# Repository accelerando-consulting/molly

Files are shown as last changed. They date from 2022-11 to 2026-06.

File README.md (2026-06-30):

# Molly - an i2c keypad module

This is intended either to fit your existing microcontroller or be added to an off the
shelf microcontroller board to make  a standalone keypad (eg the TTGO T7-S3 is a good choice of board).

Theres some simple python code in here, but
you should probably consider the [ZMK firmware](https://github.com/zmkfirmware/zmk) as the best starting point.

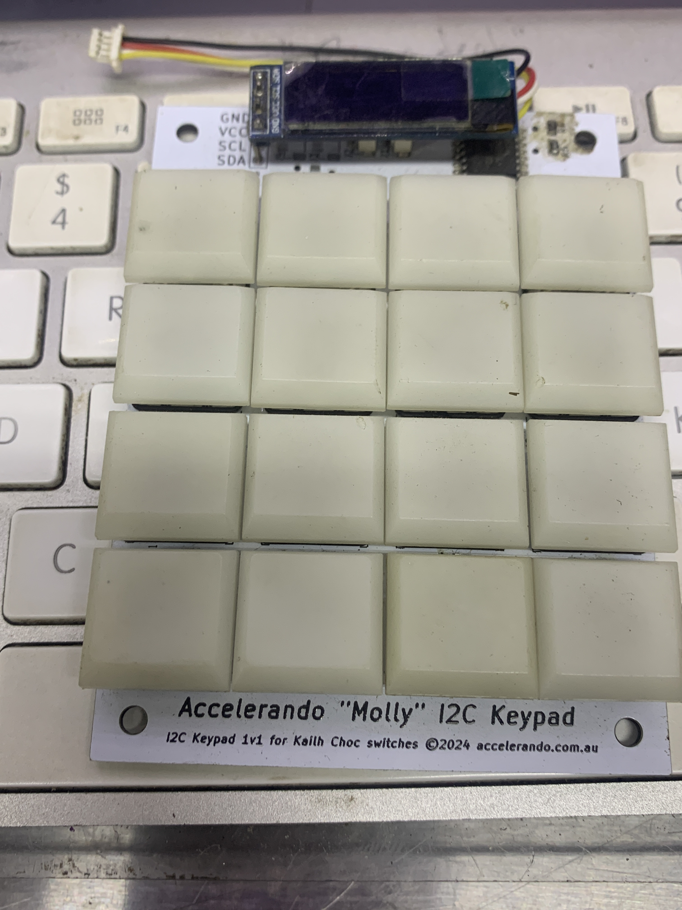
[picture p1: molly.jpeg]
Photograph of the assembled Molly PCB


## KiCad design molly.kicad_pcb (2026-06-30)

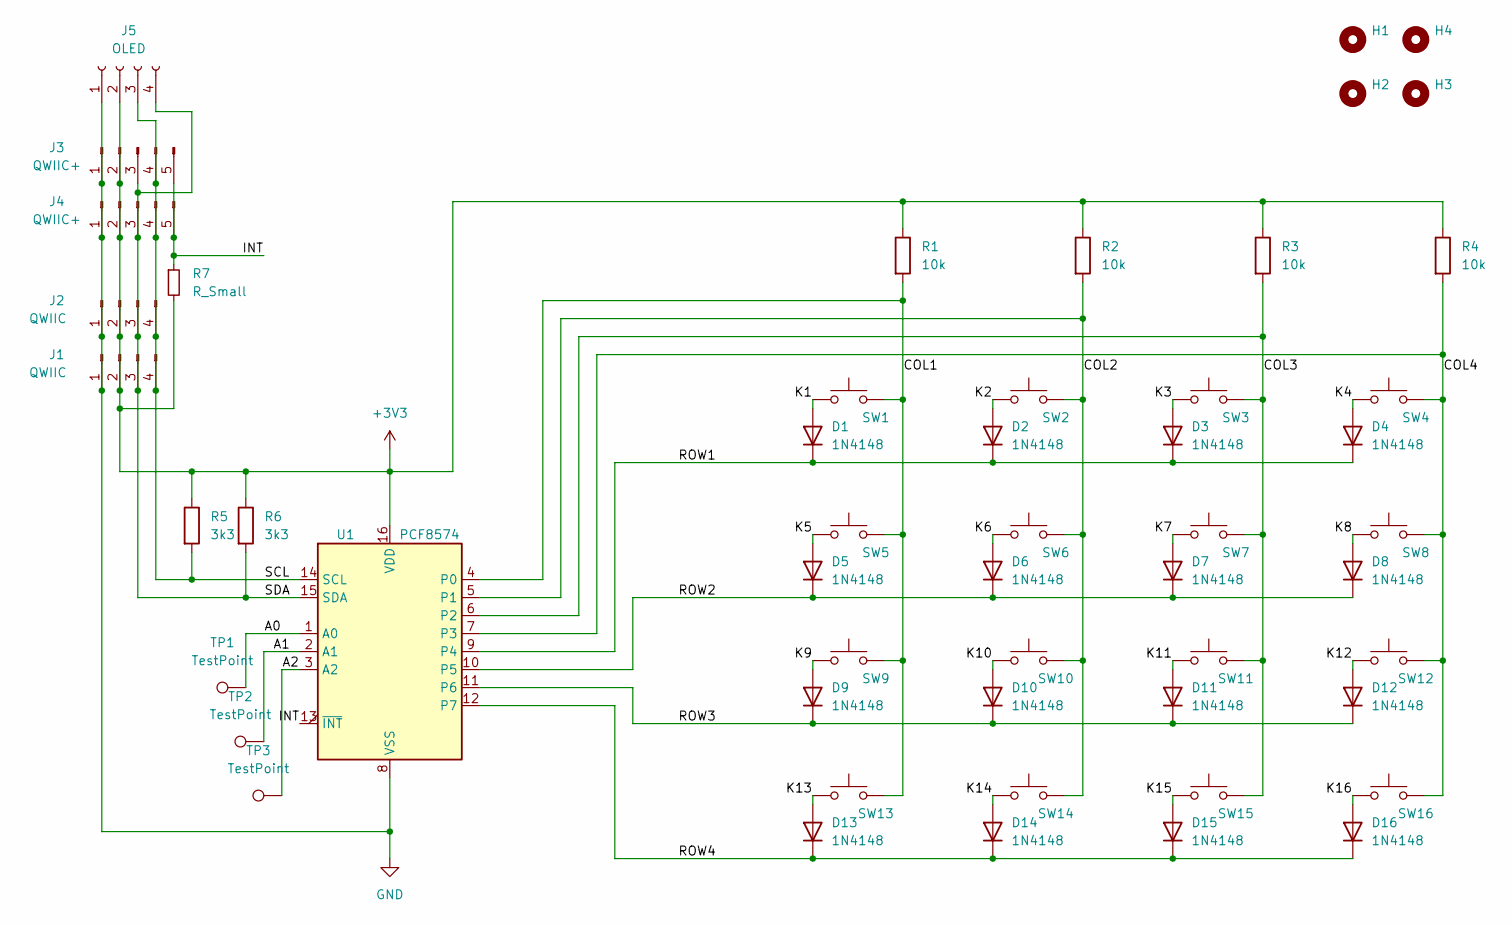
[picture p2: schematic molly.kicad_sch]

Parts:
D1, D2, D3, D4, D5, D6, D7, D8, D9, D10, D11, D12, D13, D14, D15, D16: 1N4148; D_0805_2012Metric
H1, H2, H3, H4: MountingHole; MountingHole_3.2mm_M3
J1, J2: QWIIC; JST_SH_BM04B-SRSS-TB_1x04-1MP_P1.00mm_Vertical
J3, J4: QWIIC+; JST_SH_BM05B-SRSS-TB_1x05-1MP_P1.00mm_Vertical
J5: OLED; PinSocket_1x04_P2.54mm_Vertical
R1, R2, R3, R4: 10k; R_0805_2012Metric
R5, R6: 3k3; R_0805_2012Metric
R7: R_Small; R_0805_2012Metric
SW1, SW2, SW3, SW4, SW5, SW6, SW7, SW8, SW9, SW10, SW11, SW12, SW13, SW14, SW15, SW16: Cherry MX; SW_PG1350
TP1, TP2, TP3: TestPoint; TestPoint_THTPad_2.0x2.0mm_Drill1.0mm
U1: PCF8574; SOIC-16W_7.5x10.3mm_P1.27mm

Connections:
+3V3: J1.2, J2.2, J3.2, J4.2, J5.2, R1.1, R2.1, R3.1, R4.1, R5.1, R6.1, R7.2, U1.16 (VDD)
/A0: TP1.1, U1.1 (A0)
/A1: TP2.1, U1.2 (A1)
/A2: TP3.1, U1.3 (A2)
/COL1: R1.2, SW1.2, SW5.2, SW9.2, SW13.2, U1.4 (P0)
/COL2: R2.2, SW2.2, SW6.2, SW10.2, SW14.2, U1.5 (P1)
/COL3: R3.2, SW3.2, SW7.2, SW11.2, SW15.2, U1.6 (P2)
/COL4: R4.2, SW4.2, SW8.2, SW12.2, SW16.2, U1.7 (P3)
/INT: J3.5, J4.5, R7.1, U1.13 (~INT)
/K1: D1.2 (A), SW1.1
/K2: D2.2 (A), SW2.1
/K3: D3.2 (A), SW3.1
/K4: D4.2 (A), SW4.1
/K5: D5.2 (A), SW5.1
/K6: D6.2 (A), SW6.1
/K7: D7.2 (A), SW7.1
/K8: D8.2 (A), SW8.1
/K9: D9.2 (A), SW9.1
/K10: D10.2 (A), SW10.1
/K11: D11.2 (A), SW11.1
/K12: D12.2 (A), SW12.1
/K13: D13.2 (A), SW13.1
/K14: D14.2 (A), SW14.1
/K15: D15.2 (A), SW15.1
/K16: D16.2 (A), SW16.1
/ROW1: D1.1 (K), D2.1 (K), D3.1 (K), D4.1 (K), U1.9 (P4)
/ROW2: D5.1 (K), D6.1 (K), D7.1 (K), D8.1 (K), U1.10 (P5)
/ROW3: D9.1 (K), D10.1 (K), D11.1 (K), D12.1 (K), U1.11 (P6)
/ROW4: D13.1 (K), D14.1 (K), D15.1 (K), D16.1 (K), U1.12 (P7)
/SCL: J1.4, J2.4, J3.4, J4.4, J5.3, R5.2, U1.14 (SCL)
/SDA: J1.3, J2.3, J3.3, J4.3, J5.4, R6.2, U1.15 (SDA)
GND: J1.1, J2.1, J3.1, J4.1, J5.1, U1.8 (VSS)

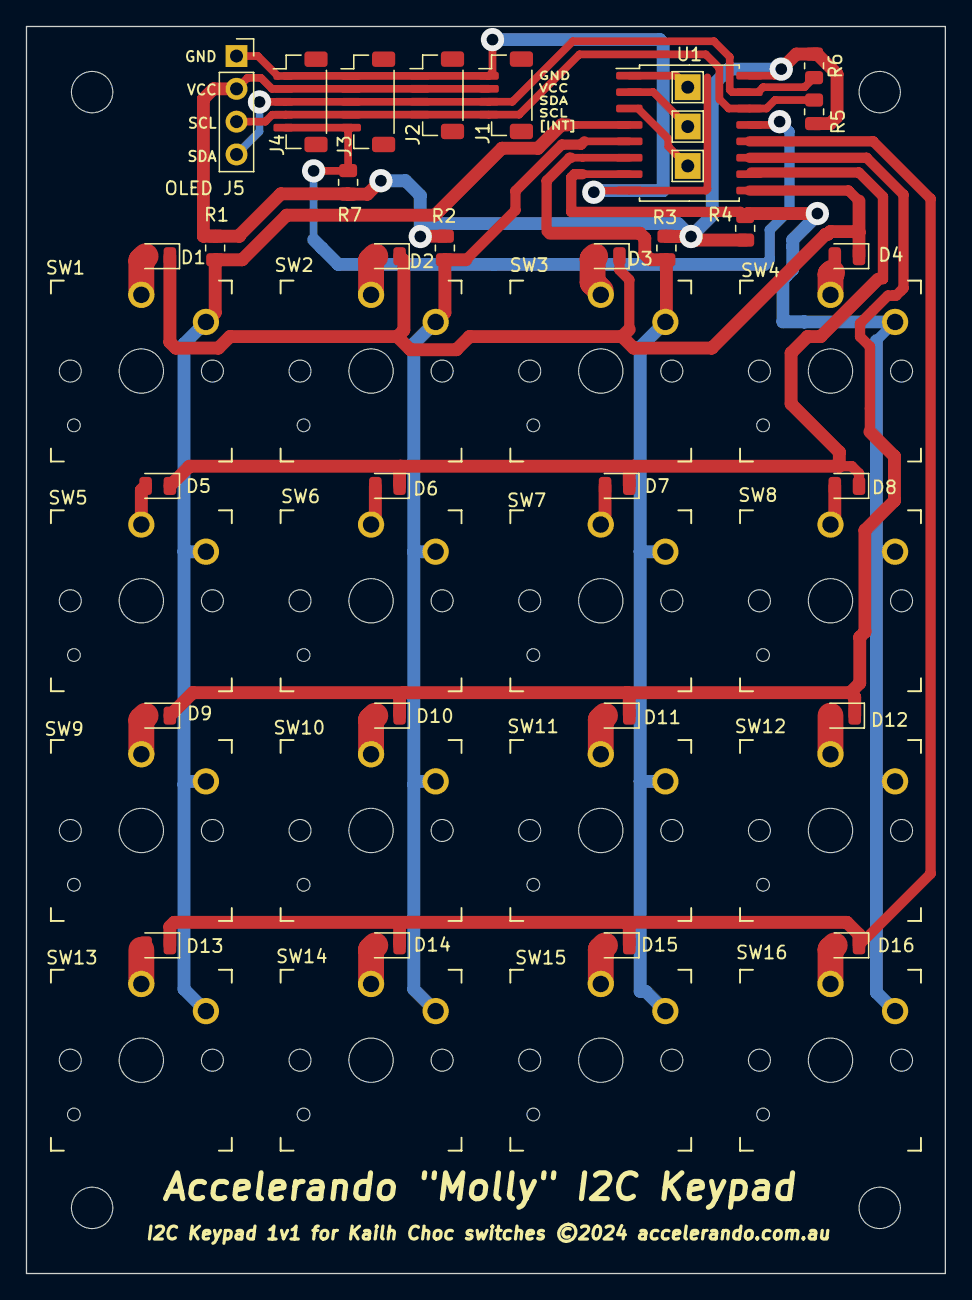
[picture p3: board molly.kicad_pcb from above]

Board: 2 copper layers, 71.1 x 96.5 mm, 52 parts (0 on the bottom side), 32 nets.

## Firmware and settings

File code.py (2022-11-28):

print("Jello World!")

import time

import board
import usb_hid
from adafruit_hid.keyboard import Keyboard
from adafruit_hid.keycode import Keycode

print("scanning i2c")
i2c = board.I2C()

while not i2c.try_lock():
    pass
i2c_addrs = i2c.scan()
i2c.unlock()

i2c_sensors = []
for addr in i2c_addrs:
    if addr < 32: continue
    print("I2C device found at:",hex(addr))
    i2c_sensors.append({
        'addr': addr,
        #'device': adafruit_pcf8574.PCF8574(i2c_bus=i2c, addrress=addr),
        'state': 0,
    })
print("Sensor table is ", i2c_sensors)

print("creating keyboard")
kbd = Keyboard(usb_hid.devices)

def read_sensor(addr, bus=i2c):
    regs = bytearray(1)
    bus.readfrom_into(address=addr, buffer=regs)
    return regs[0]

def write_sensor(addr, value, bus=i2c):
    print("write_sensor({}, {})".format(hex(addr), hex(value)))
    regs = bytearray(1)
    regs[0] = value
    while not bus.try_lock():
        pass
    bus.writeto(addr, regs)
    bus.unlock()
    

def poll_sensors(bus=i2c, sensors=i2c_sensors):

    #print("lock bus", bus)
    while not bus.try_lock():
        pass
    
    for s in sensors:
        #print("poll sensor", s)
        b = read_sensor(s['addr'])
        if (b != s['state']):
            s['state']=b
            print("Device at {} has new state {}".format(s['addr'], hex(s['state'])))
                
    #print("release bus", bus)
    bus.unlock()

key_table = [
    [56, 0, False, Keycode.UP_ARROW],
]

def get_sensor(addr, sensors=i2c_sensors):
    for s in sensors:
        if s["addr"]==addr:
            return s
    return None

def is_pressed(bits, pos):
    return ((bits & (1<<(pos*2)))==0)

def scan_keys(bus=i2c, sensors=i2c_sensors, keys=key_table):
    for k in keys:
        (addr, pos ,pressed, code) = k
        #print("Examine key addr={} pos={} pressed={} code={}".format(addr,pos,pressed,code))
        s = get_sensor(addr)
        if s==None: continue
        state = s['state']
        
        if not pressed and is_pressed(state, pos):
            # press detected, light up the led and send a keystroke
            print("Keypress detected state=",hex(state))
            s['state'] &= ~(1<<(1+pos*2)) # led low (sinking current)
            s['state'] |= (1<<(0+pos*2)) # key high (input pullup)
            write_sensor(addr, s['state'])
            kbd.send(code)
            k[2]=True # pressed
        elif pressed and not is_pressed(state, pos):
            # release detected, turn off the LED
            print("Release detected state=",hex(state))
            s['state'] |= (1<<(1+pos*2)) # led high (not sinking current)
            s['state'] |= (1<<(0+pos*2)) # key high (input pullup)
            write_sensor(addr, s['state'])
            k[2]=False # released


print("scan loop")
while True:
    poll_sensors()
    scan_keys()
    time.sleep(0.1)
    

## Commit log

2022-11-28 Molly v1, a 16 key i2c macropad
    [molly.kicad_pcb, molly.kicad_sch]
2026-06-30 Updated for more recent kicads, fix bassackwards screen pinout
    [molly.kicad_pcb, molly.kicad_sch]

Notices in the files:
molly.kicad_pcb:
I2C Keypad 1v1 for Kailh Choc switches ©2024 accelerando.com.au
